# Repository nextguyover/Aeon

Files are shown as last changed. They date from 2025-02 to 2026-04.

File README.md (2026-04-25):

# Aeon

Aeon

Aeon is a solar-powered colour e-ink photo frame designed around the [7.3inch Spectra 6](https://www.waveshare.com/7.3inch-e-paper-hat-e.htm) e-ink display. Powered using energy harvesting, Aeon achieves indefinite operation when placed in a bright indoor environment.

This repository contains the following design files for Aeon. 

- [Firmware](firmware)
- [Image Conversion Script](image_conversion)
- [Schematic and PCB Design](schematic_and_PCB)

See the the [blogpost](https://insertnewline.com/blog/aeon/) for a full write-up and additional file downloads.

Current Aeon version is v2.0, available on the [main branch](https://github.com/nextguyover/Aeon/tree/main). See older versions below:
- [v1.4](https://github.com/nextguyover/Aeon/tree/v1.4) - Using discontinued [7.3inch ACeP](https://www.waveshare.com/7.3inch-e-paper-hat-f.htm) e-ink display

## Firmware

The `/firmware` directory contains the firmware for the STM32 microcontroller.

### Flashing

Before flashing the firmware, the option bytes of the STM32 must be set. Using STM32CubeProgrammer, uncheck nSWBOOT0. The option byte options should look like this:

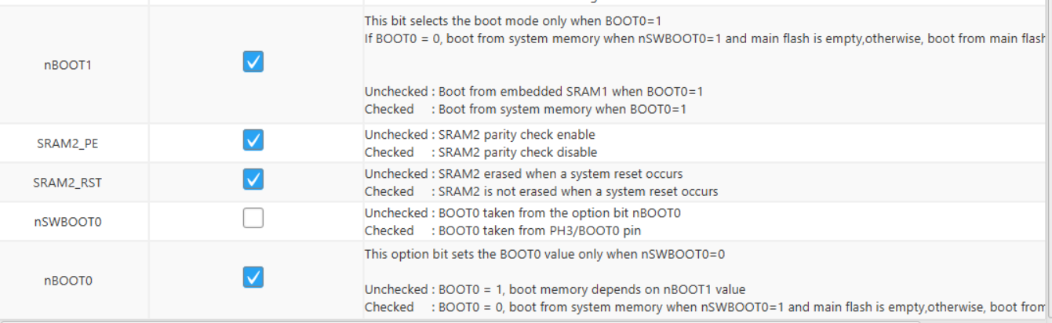
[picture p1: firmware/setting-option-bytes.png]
option bytes


Next, flashing the firmware can be done using the STM32CubeIDE. Your STLink programmer should be connected to the programming pins on the PCB.

### Debugging

The firmware includes several debugging features. 

Any `printf` statements will be outputted to SWO, which can be read using STLink. Additionally, if debug mode is active, any logged data will be stored in an array, and written to the SD card just before going back to sleep. This debug mode is enabled by pressing and **holding** the refresh button to wake the device. The status LED will **flash rapidly** to indicate debug mode is active. Alternatively, the `DEBUG_MODE_FORCE_EN` flag in `main.h` forces debug mode to be enabled. This should be disabled during normal operation to prevent excessive SD card writes.

The `BATT_LOGGING` flag in logs to `/logfiles/batt-charge.csv` on the SD card. This only appends a new line to the file on each wake cycle, so it is safe to leave on for extended periods of time.

### ADC Calibration

The ADC for the battery voltage measurement should be calibrated as the accuracy of different STM32 chips can vary. The calibration process must be done manually by changing [this](/firmware/Core/Src/aeon.c#L108) value in the `aeon.c` file.

## Image Conversion

The `/image_conversion` folder contains a Python script to convert images to the SLIC format, which is the image format Aeon supports. 

### Preparation

Compile the photos you wish to display on Aeon, and save them in a directory. `.jpg`, `.png` and `.heic` files are supported. All images should be the same orientation. If a portrait orientation is chosen, rotate all portrait images 90 degrees clockwise. 

### Usage Instructions

The first step is preparing the SLIC conversion executable.

1. Git clone the SLIC repository `git clone https://github.com/bitbank2/SLIC.git`
2. Change directory `cd SLIC/linux/c_demo/`
3. Compile executable with `make`
4. Copy the executable to the `/image_conversion` directory

Next, install the required Python packages with `pip install -r requirements.txt`.

To convert a directory of images, run `python convert.py <input_dir>` where `<input_dir>` is the directory containing the images to convert. The converted images will be saved in a new directory named `img_out`.

Format the SD card in FAT32. The generated `.slc` files can then be copied to the `/images` directory of the SD card. *Do not rename the generated files.*

## Schematic and PCB Design

The `/schematic_and_PCB` directory contains the KiCad schematic and PCB design files for Aeon.

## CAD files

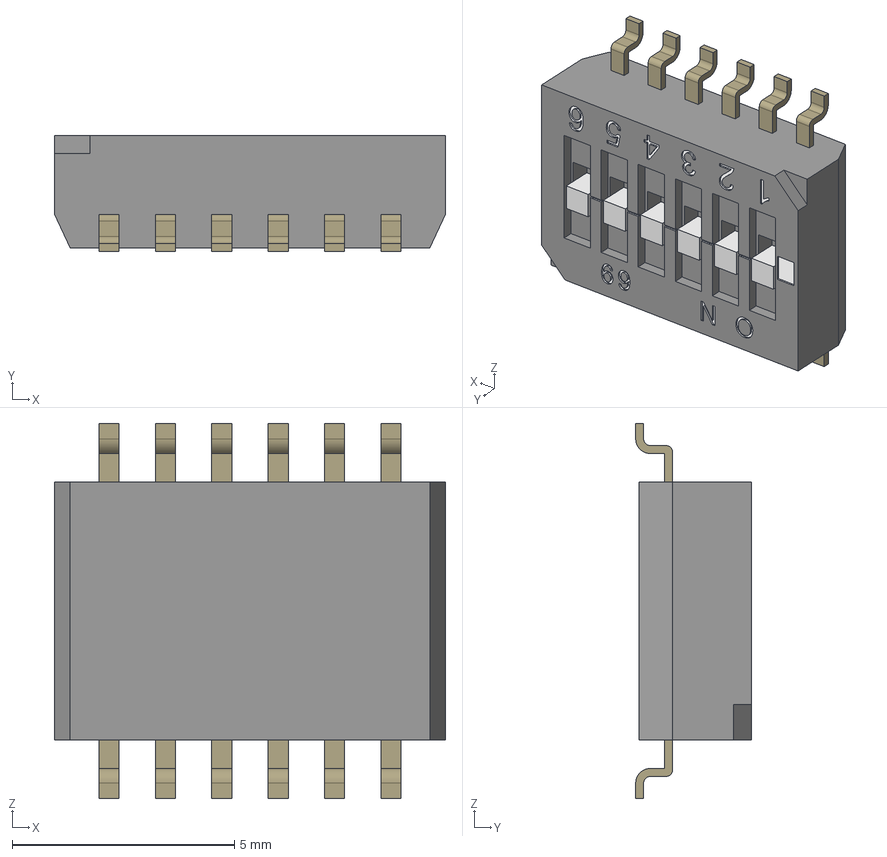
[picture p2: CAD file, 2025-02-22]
schematic_and_PCB/Symbols External/218-6LPSRF/218-6LPSRF.stp
8.79 x 2.60 x 8.44 mm

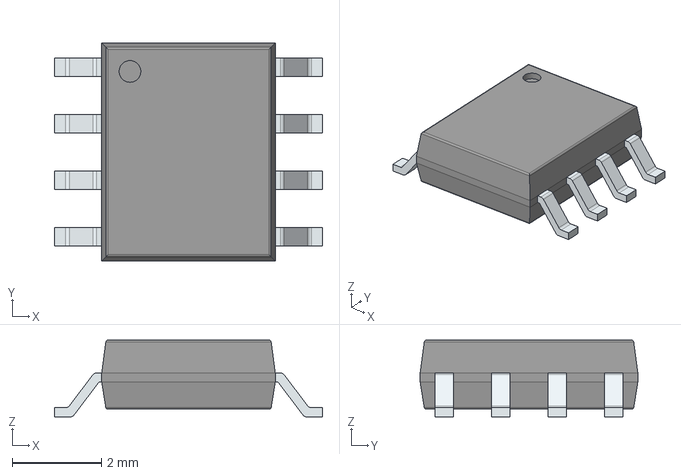
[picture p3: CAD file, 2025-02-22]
schematic_and_PCB/Symbols External/LIB_FM25L04B-GTR/FM25L04B-GTR/3D/FM25L04B-GTR.stp
6.02 x 4.89 x 1.73 mm
PinsArrayLR

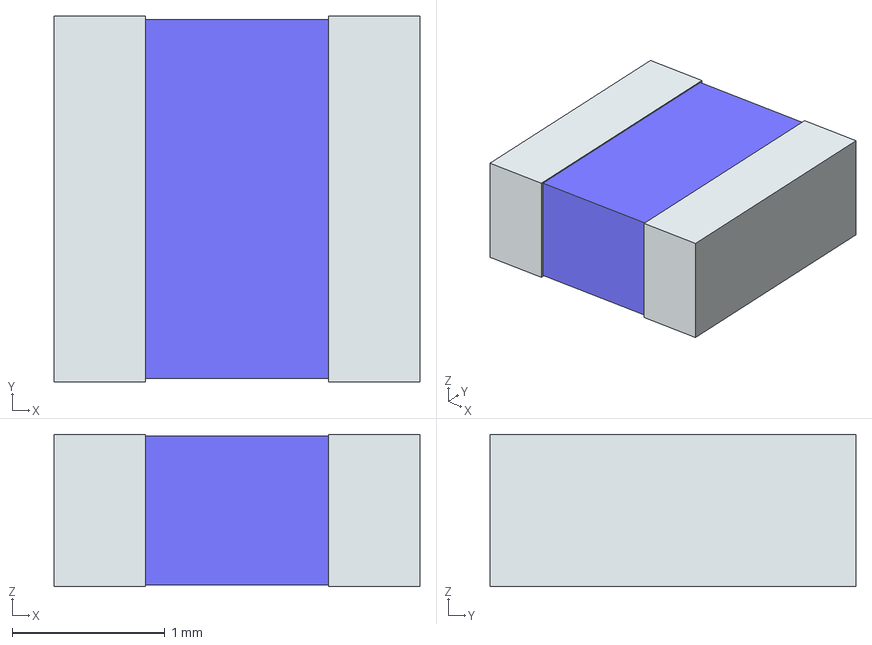
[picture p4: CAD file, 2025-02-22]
schematic_and_PCB/Symbols External/LIB_NRH2410T220MN- inductor 2410/NRH2410T220MN/3D/NRH2410T220MN.stp
2.40 x 2.40 x 1.00 mm
term1
term2

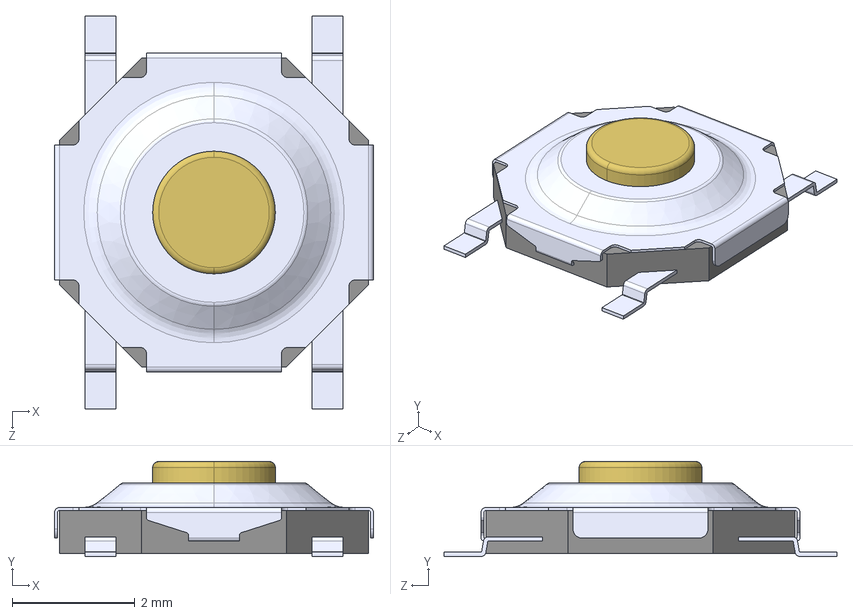
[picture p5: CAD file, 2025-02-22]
schematic_and_PCB/Symbols External/LIB_PTS526_SK15_SMTR2_LFS/PTS526_SK15_SMTR2_LFS.stp
5.20 x 1.55 x 6.40 mm

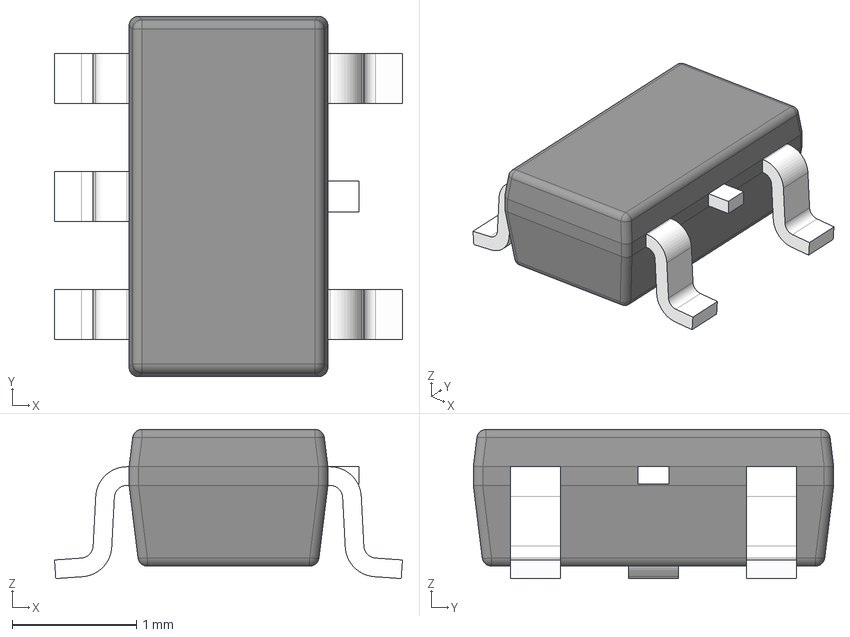
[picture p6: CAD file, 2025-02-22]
schematic_and_PCB/Symbols External/LIB_TPS7A0233PDBVR/TPS7A0233PDBVR.stp
2.80 x 2.90 x 1.20 mm
BODY-SOT
LEAD-SOT x 5
LEAD-DUMMY

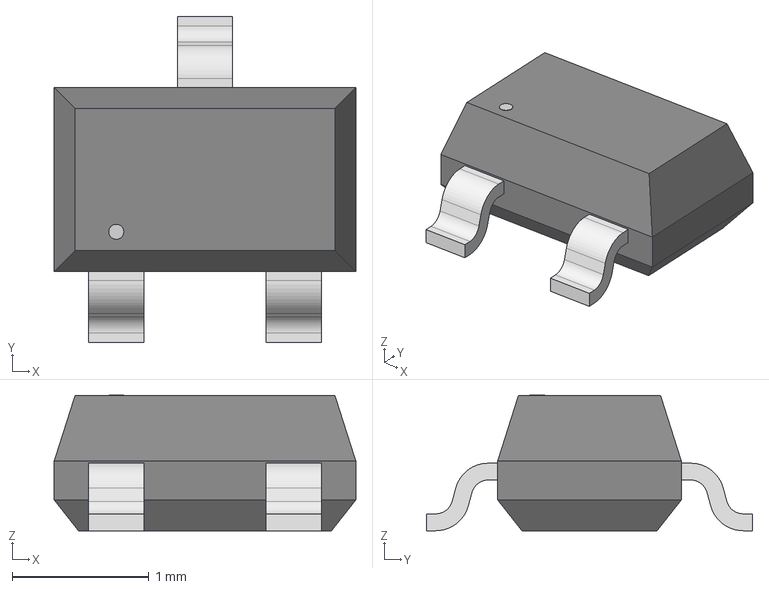
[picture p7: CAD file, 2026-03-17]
schematic_and_PCB/Symbols External/SI1308EDL_T1_GE3/MOSFET_8EDL-T1-GE3_VIS.step
2.21 x 2.39 x 0.993 mm

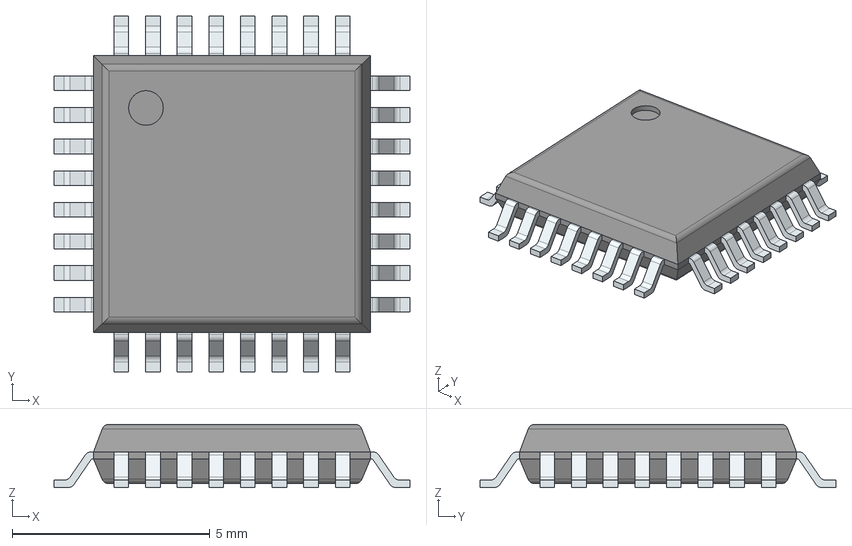
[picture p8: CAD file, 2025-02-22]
schematic_and_PCB/Symbols External/STM32L412K8T6/3D/STM32L412K8T6.stp
9.00 x 9.00 x 1.60 mm
PinsArrayLR
PinsArrayTB

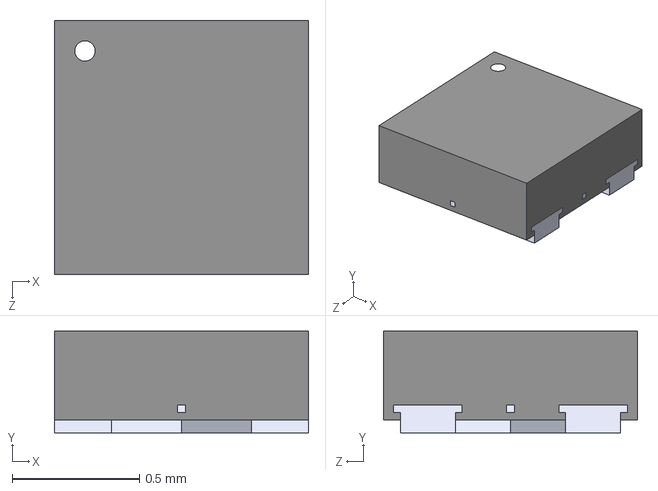
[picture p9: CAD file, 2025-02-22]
schematic_and_PCB/Symbols External/TPS7A0233PDQNR/TPS7A0233PDQNR.step
1.00 x 0.4 x 1.00 mm

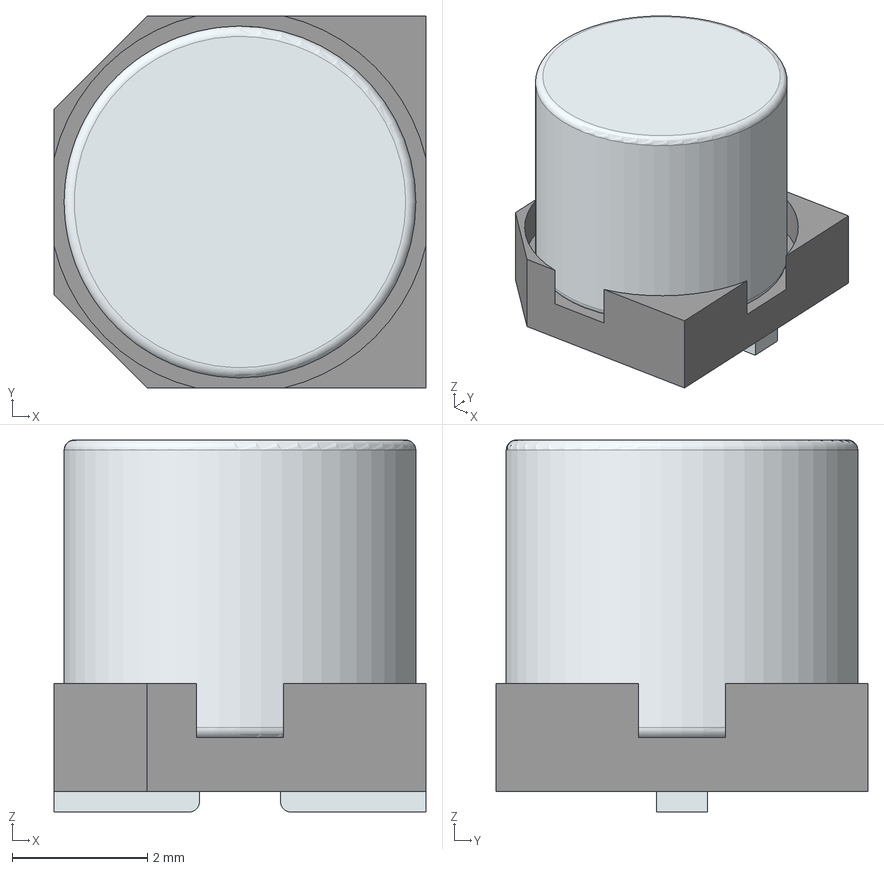
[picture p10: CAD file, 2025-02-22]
schematic_and_PCB/Symbols External/100uF SMD Electrolytic/865080142007.stp
5.50 x 5.50 x 5.50 mm
Base
Pin1Fillet
Pin2Fillet

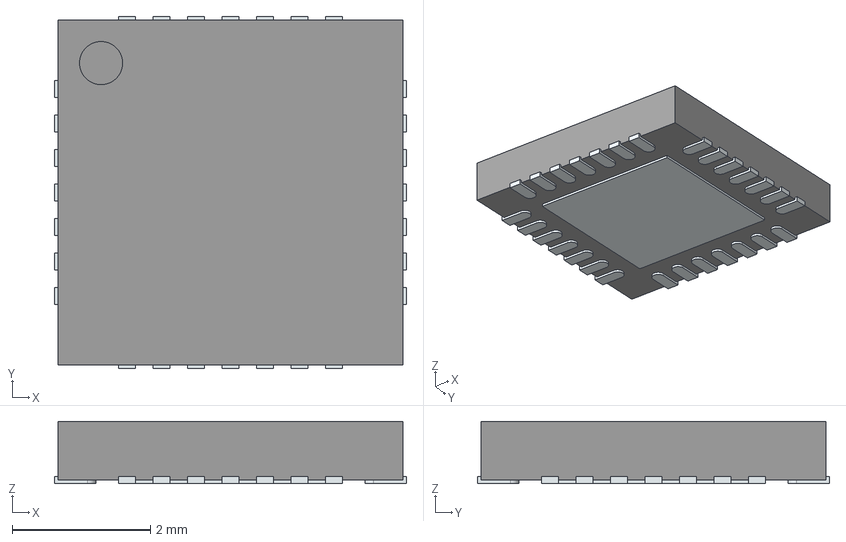
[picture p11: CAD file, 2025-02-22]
schematic_and_PCB/Symbols External/AEM10941-QFN/AEM10941-QFN.stp
5.10 x 5.10 x 0.9 mm
ThermalPin
PinsArrayLR
PinsArrayTB

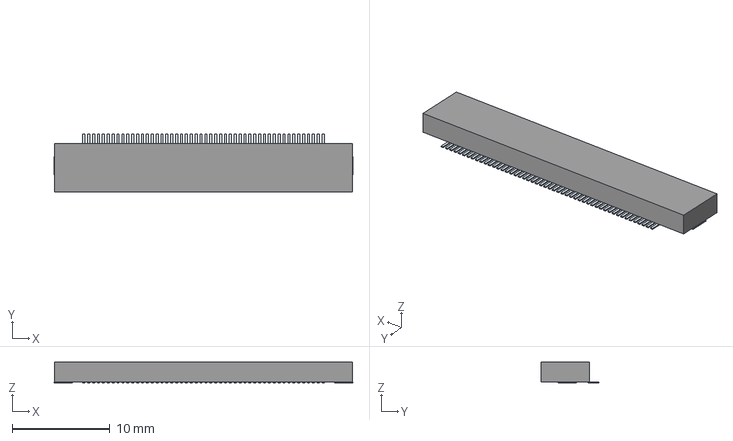
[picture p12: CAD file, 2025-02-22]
schematic_and_PCB/Symbols External/FPC_CONN_2/62684-50110E9ALF.stp
30.6 x 5.97 x 2.10 mm
Pins

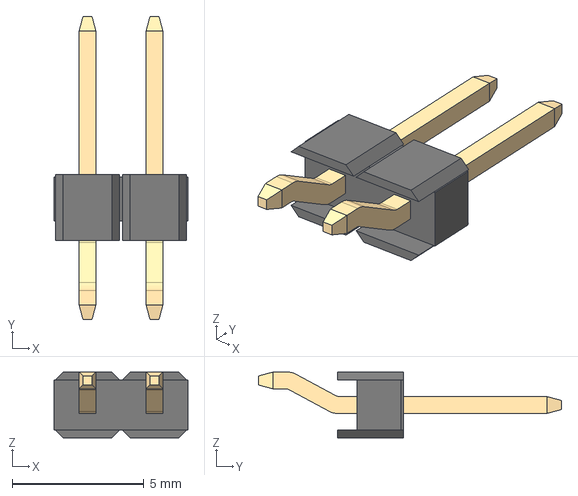
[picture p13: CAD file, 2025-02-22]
schematic_and_PCB/Symbols External/LIB_M20-8890245 - 2-pin-smd connector/M20-8890245/3D/M20-8890245.stp
5.08 x 11.5 x 2.50 mm
M20-88902_MOULD
M20-889_CONTACT x 2

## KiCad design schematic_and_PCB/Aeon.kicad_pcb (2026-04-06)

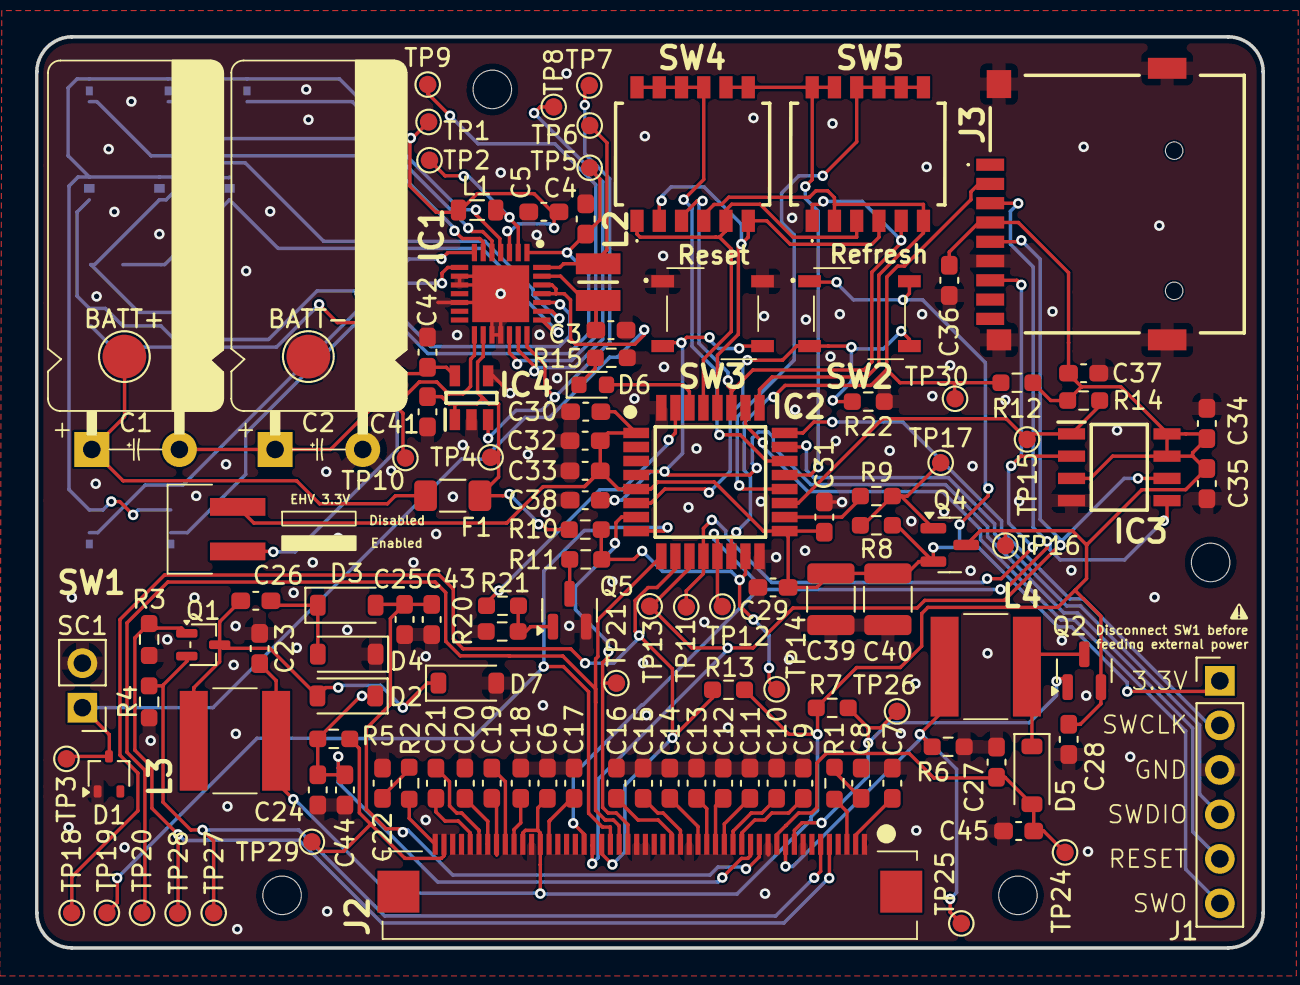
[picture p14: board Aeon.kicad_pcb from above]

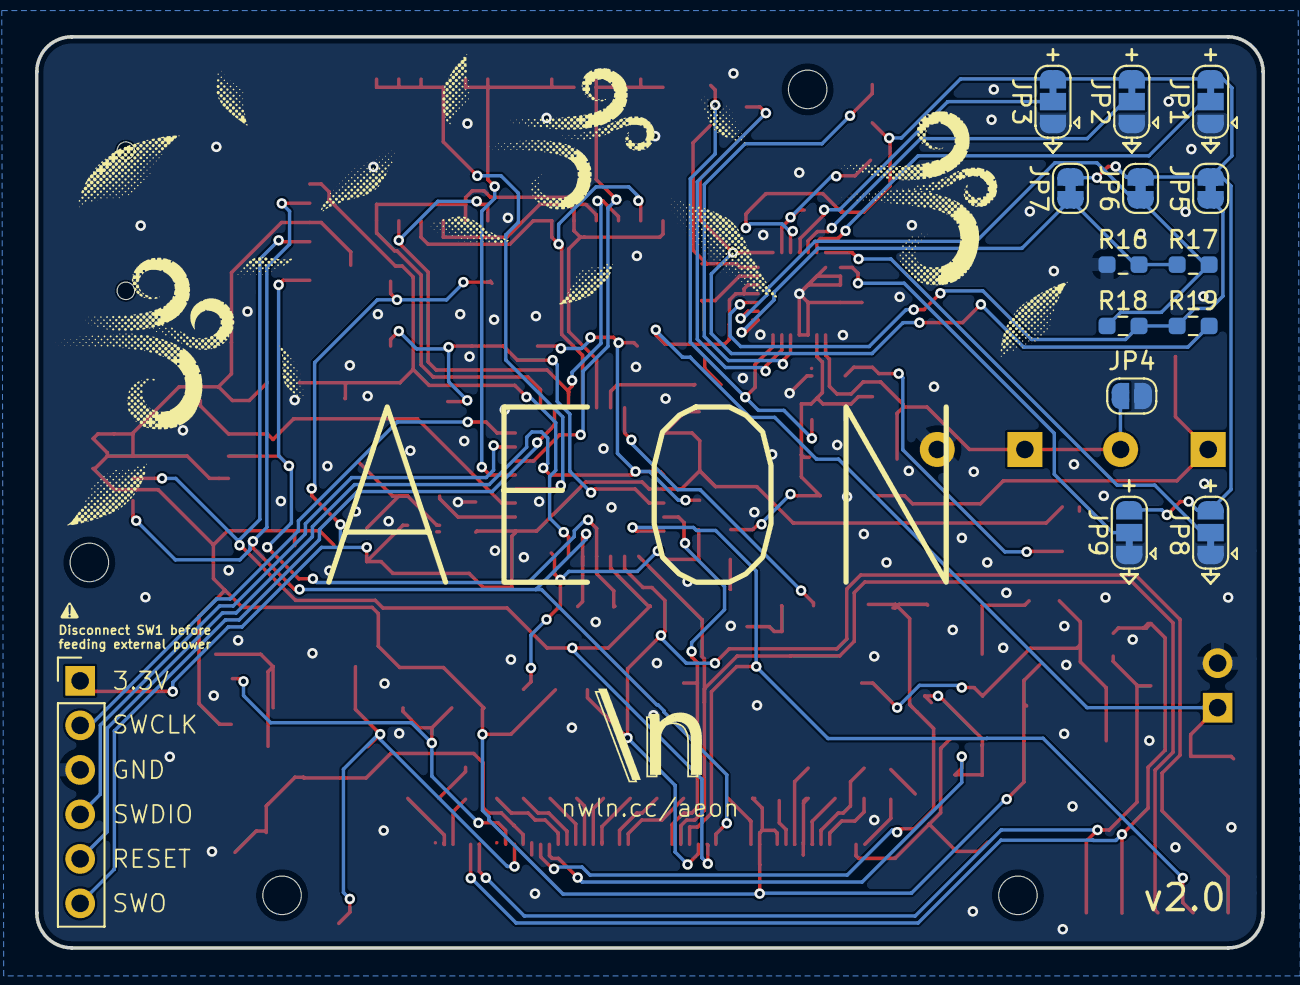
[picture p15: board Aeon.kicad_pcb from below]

Board: 2 copper layers, 70.0 x 52.0 mm, 135 parts (13 on the bottom side), 84 nets.

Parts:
BATT+: TestPoint_Pad_D2.5mm
BATT-: TestPoint_Pad_D2.5mm
C1, C2: 6F 2.7V; SUPERCAP
C3, C5: 10uF; C_0603_1608Metric_Pad1.08x0.95mm_HandSolder
C4: 22uF; C_0603_1608Metric_Pad1.08x0.95mm_HandSolder
C6, C43, C44, C45: 100nF/50V; C_0603_1608Metric_Pad1.08x0.95mm_HandSolder
C7, C22, C23: 4.7uF/25V; C_0603_1608Metric_Pad1.08x0.95mm_HandSolder
C8: 0.47uF/25V; C_0603_1608Metric_Pad1.08x0.95mm_HandSolder
C9, C10, C11, C12, C13, C14, C24, C25, C26, C27: 10uF/25V; C_0603_1608Metric_Pad1.08x0.95mm_HandSolder
C15, C16, C18, C19, C20, C21: 1uF/50V; C_0603_1608Metric_Pad1.08x0.95mm_HandSolder
C17: 2.2uF/6.3V; C_0603_1608Metric_Pad1.08x0.95mm_HandSolder
C28, C29: 4.7uF/10V; C_0603_1608Metric_Pad1.08x0.95mm_HandSolder
C30, C31, C35, C36: 100nF/10V; C_0603_1608Metric_Pad1.08x0.95mm_HandSolder
C32: 10nF/10V; C_0603_1608Metric_Pad1.08x0.95mm_HandSolder
C33: 1uF/10V; C_0603_1608Metric_Pad1.08x0.95mm_HandSolder
C34, C37: 10uF/10V; C_0603_1608Metric_Pad1.08x0.95mm_HandSolder
C38: 0.1uF/10V; C_0603_1608Metric_Pad1.08x0.95mm_HandSolder
C39, C40: 100uF/10V; C_1210_3225Metric
C41, C42: 1uF; C_0603_1608Metric_Pad1.08x0.95mm_HandSolder
D1: Zener_5V; SOT-323_SC-70
D2, D3, D4, D5: MBR0530; D_SOD-123
D6: DEBUG_LED; LED_0603_1608Metric
D7: BZT52C27; D_SOD-123
F1: 750mA Polyfuse; R_1206_3216Metric_Pad1.30x1.75mm_HandSolder
IC1: AEM10941-QFN; QFN50P500X500X90-29N-D
IC2: STM32L412K8T6; QFP80P900X900X160-32N
IC3: FM25L04B-GTR; SOIC127P602X173-8N
IC4: TPS7A0233PDBVR; SOT95P280X145-5N
J1: Conn_01x06_Pin; PinHeader_1x06_P2.54mm_Vertical
J2: FH34SRJ-50S-0.5SH50 - Colour E-Paper; FPC_CONN_2
J3: Micro_SD_Card; MICROSDCARD
JP1, JP2, JP3: SolderJumper_3_Open; SolderJumper-3_P1.3mm_Bridged2Bar23_RoundedPad1.0x1.5mm
JP4: SolderJumper_2_Open; SolderJumper-2_P1.3mm_Open_RoundedPad1.0x1.5mm
JP5, JP6, JP7: SolderJumper_2_Open; SolderJumper-2_P1.3mm_Bridged_RoundedPad1.0x1.5mm
JP8, JP9: SolderJumper_3_Open; SolderJumper-3_P1.3mm_Bridged2Bar12_RoundedPad1.0x1.5mm
L1: 10uH/50mA; L_0805_2012Metric
L2: 22uH/115mA; INDC2424X100N
L3, L4: 10uH/1A; NR6012T100ME_INDUCTOR_6012
Q1: SI1308EDL; SOT-323_SC-70
Q2, Q4: SI2301CDS-T1-E3; SOT-23
Q5: BSS138; SOT-23
R1, R2, R5: 0R; R_0603_1608Metric_Pad0.98x0.95mm_HandSolder
R3, R7, R8, R20: 1M; R_0603_1608Metric_Pad0.98x0.95mm_HandSolder
R4, R6: 0.2R; R_0603_1608Metric_Pad0.98x0.95mm_HandSolder
R9, R10, R21: 4.7K; R_0603_1608Metric_Pad0.98x0.95mm_HandSolder
R11, R12, R13, R14, R22: 10K; R_0603_1608Metric_Pad0.98x0.95mm_HandSolder
R15: 1K; R_0603_1608Metric_Pad0.98x0.95mm_HandSolder
R16, R17, R18, R19: X; R_0603_1608Metric_Pad0.98x0.95mm_HandSolder
SC1: EHV_SRC_Cell; PinHeader_1x02_P2.54mm_Vertical
SW1: SW_EHV_EN; SMD_2x_PIN_HEADER
SW2: REFRESH_BTN; PTS526SMG15JSMTR2LFS
SW3: RESET_BTN; PTS526SMG15JSMTR2LFS
SW4, SW5: SW_DIP_x06_SMD_1.27; 2186LPSRF
TP1, TP2, TP3, TP4, TP5, TP6, TP7, TP8, TP9, TP10, TP11, TP12, TP13, TP14, TP15, TP16, TP17, TP18, TP19, TP20, TP21, TP24, TP25, TP26, TP27, TP28, TP29, TP30: TestPoint_Pad_D1.0mm

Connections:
+3.3V: C29.2, C30.2, C31.2, C32.1, C33.2, C39.2, C40.2, IC2.1 (VDD_1), IC2.5 (VDDA/VREF+), IC2.17 (VDD_2), J1.1, Q4.2 (S), R8.1, SW1.2, SW2.1
+3.3V AUX: C6.2, C23.2, C28.2, C34.1, C35.2, C36.1, C37.2, IC3.3 (~WP), IC3.7 (~HOLD), IC3.8 (VDD), J2.38 (VDD), J2.40 (VDDIO), J3.4 (VDD), L3.1, Q2.2 (S), Q4.3 (D), R7.2, R12.1, R13.1, R14.1, TP16.1
AUX_PWR_EN: IC2.18 (PA8), R9.1
BATT_VDIV_EN: IC2.31 (PH3-BOOT0), R21.1
DISP_BUSY: IC2.9 (PA3), J2.29 (BUSY_N), TP20.1
DISP_CS: IC2.10 (PA4), J2.31 (CS#), R13.2, TP18.1
DISP_D/C: IC2.8 (PA2), J2.30 (D/C#), TP19.1
DISP_GDRC: J2.9 (GDRC), Q2.1 (G), R7.1, TP26.1
DISP_GDRH: J2.5 (GDRH), Q1.1 (G), R3.2, TP28.1
DISP_MOSI: IC2.13 (PA7), IC3.5 (SI), J2.33 (SIO), J3.3 (CMD), TP12.1
DISP_RESEC: J2.10 (RESEC), L4.1, R6.2, TP25.1
DISP_RESEH: J2.6 (RESEH), Q1.2 (S), R4.2, TP27.1
DISP_RST: IC2.7 (PA1), J2.28 (RES#), TP21.1
DISP_SCLK: IC2.11 (PA5), IC3.6 (SCK), J2.32 (SCL), J3.5 (CLK), TP13.1
DISP_VGH: J2.49 (VGH), R5.2, TP29.1
DISP_VGL: C25.2, C43.2, D3.2 (A), J2.13 (VGL)
DISP_VPC: C27.2, C45.2, D5.2 (A), J2.11 (VPC), TP24.1
DISP_VPH: C24.2, C44.2, D2.1 (K), J2.14 (VPH), R5.1
EHV_BATT: C41.1, F1.1, IC1.16 (BATT), IC4.1 (IN), R10.1, TP4.1
EHV_BOOST: C4.2, IC1.1 (BOOST), R19.2, TP5.1
EHV_BUCK: C5.2, IC1.3 (BUCK), JP1.3 (B), JP2.3 (B), JP3.3 (B), JP5.2 (B), JP6.2 (B), JP7.2 (B), JP8.3 (B), JP9.3 (B), L1.1, TP1.1
EHV_LDO_EN: IC1.21 (STATUS[0]), IC4.3 (EN), TP7.1
EHV_SRC: D1.3 (K), IC1.25 (SRC), IC1.26 (SRC), SC1.1 (+), TP3.1
EHV_SWBOOST: IC1.28 (SWBOOST), L2.1, TP6.1
EHV_SWBUCK: IC1.2 (SWBUCK), L1.2, TP2.1
FRAM_CS: IC2.19 (PA9), IC3.1 (~CS), R14.2, TP15.1
FRAM_MISO: IC2.12 (PA6), IC3.2 (SO), J3.7 (DAT0), TP11.1
GND: BATT-.1, C2.2, C3.2, C4.1, C5.1, C6.1, C7.1, C8.1, C9.1, C10.1, C11.1, C12.1, C13.1, C14.1, C15.1, C16.1, C17.1, C18.1, C20.1, C22.1, C23.1, C24.1, C25.1, C27.1, C28.1, C29.1, C30.1, C31.1, C32.2, C33.1, C34.2, C35.1, C36.2, C37.1, C38.2, C39.1, C40.1, C41.2, C42.1, C43.1, C44.1, C45.1, D1.1 (A), D4.1 (K), D7.2 (A), IC1.9 (FB_PRIM_D), IC1.10 (FB_PRIM_U), IC1.12 (ENHV), IC1.17 (PRIM), IC1.18 (ENLV), IC1.29 (PAD_(GND)), IC2.16 (VSS_1), IC2.32 (VSS_2), IC3.4 (VSS), IC4.2 (GND), IC4.4 (NC), J1.3, J2.8 (GND), J2.12 (GND), J2.21 (GNDA), J2.26 (BS0), J2.27 (BS1), J2.39 (GND), J3.6 (VSS), J3.9 (SHIELD), JP1.1 (A), JP2.1 (A), JP3.1 (A), JP4.1 (A), JP8.1 (A), JP9.1 (A), Q5.2 (S), R3.1, R4.1, R6.1, R15.2, R16.1, R20.2, R22.1, SC1.2 (-), SW3.1
unnamed: BATT+.1, C1.1, F1.2
unnamed: C8.2, R1.1
unnamed: C22.2, R2.1
unnamed: C26.2, D2.2 (A), D7.1 (K), L3.2, Q1.3 (D)
unnamed: C26.1, D3.1 (K), D4.2 (A)
unnamed: D5.1 (K), L4.2, Q2.3 (D)
unnamed: D6.2 (A), IC2.30 (PB7)
unnamed: D6.1 (K), R15.1
unnamed: C1.2, C2.1, IC1.15 (BAL), JP4.2 (B), TP10.1
unnamed: C3.1, IC1.27 (BUFSRC), L2.2
unnamed: IC1.6 (CFG[0]), JP1.2 (C)
unnamed: IC1.5 (CFG[1]), JP2.2 (C)
unnamed: IC1.4 (CFG[2]), JP3.2 (C)
unnamed: IC1.8 (SELMPP[0]), JP9.2 (C)
unnamed: IC1.7 (SELMPP[1]), JP8.2 (C)
unnamed: IC1.23 (SET_CHRDY), JP6.1 (A), R17.2, R18.1
unnamed: IC1.22 (SET_OVCH), JP7.1 (A), R16.2, R17.1
unnamed: IC1.24 (SET_OVDIS), JP5.1 (A), R18.2, R19.1
unnamed: IC1.20 (STATUS[1]), TP8.1
unnamed: IC1.19 (STATUS[2]), TP9.1
unnamed: IC2.6 (PA0-CK_IN), R22.2, SW2.2
unnamed: IC2.20 (PA10), SW5.7, SW5.8, SW5.9, SW5.10
unnamed: IC2.21 (PA11), SW4.7, SW4.8, SW5.11, SW5.12
unnamed: IC2.22 (PA12), SW4.9, SW4.10, SW4.11, SW4.12
unnamed: IC2.25 (PA15), SW4.4, SW5.2, SW5.6
unnamed: IC2.15 (PB1), R10.2, R11.1, TP14.1
unnamed: IC2.27 (PB4), SW4.3, SW5.1, SW5.5
unnamed: IC2.28 (PB5), SW4.2, SW4.6, SW5.4
unnamed: IC2.29 (PB6), SW4.1, SW4.5, SW5.3
unnamed: C42.2, IC4.5 (OUT), SW1.1
unnamed: C21.1, J2.45 (CP1N)
unnamed: C21.2, J2.46 (CP1P)
unnamed: C19.1, J2.42 (CP2N)
unnamed: C19.2, J2.43 (CP2P)
unnamed: J2.3 (FPL_VCOM), R1.2
unnamed: C15.2, J2.22 (REFN)
unnamed: C16.2, J2.23 (REFP)
unnamed: C7.2, J2.2 (TFT_VCOM)
unnamed: J2.50 (VCOMBD), R2.2
unnamed: C20.2, J2.44 (VCP1)
unnamed: C18.2, J2.41 (VCP2)
unnamed: C17.2, J2.37 (VDDDO)
unnamed: C9.2, J2.15 (VSH)
unnamed: C11.2, J2.17 (VSH_LV2)
unnamed: C10.2, J2.16 (VSH_LV)
unnamed: C12.2, J2.18 (VSL)
unnamed: C14.2, J2.20 (VSL_LV2)
unnamed: C13.2, J2.19 (VSL_LV)
unnamed: Q4.1 (G), R8.2, R9.2, TP17.1
unnamed: Q5.3 (D), R11.2
unnamed: Q5.1 (G), R20.1, R21.2
SD_CS: IC2.14 (PB0), J3.2 (DAT3/CD), R12.2, TP30.1
SOC_RST: C38.1, IC2.4 (NRST), J1.5, SW3.2
SOC_SWCLK: IC2.24 (PA14), J1.2
SOC_SWDIO: IC2.23 (PA13), J1.4
SOC_SWO: IC2.26 (PB3), J1.6

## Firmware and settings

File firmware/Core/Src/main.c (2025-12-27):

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
/* Includes ------------------------------------------------------------------*/
#include "main.h"

#include "fatfs.h"

/* USER CODE BEGIN Includes */
#include <stdarg.h>  //for va_list var arg functions
#include <stdbool.h>
#include <stdio.h>
#include <string.h>

#include "aeon.h"
#include "disp.h"
#include "fram.h"
#include "sd.h"
#include "slic.h"

/* USER CODE END Includes */

ADC_HandleTypeDef hadc1;

RNG_HandleTypeDef hrng;

RTC_HandleTypeDef hrtc;

SPI_HandleTypeDef hspi1;

/* USER CODE BEGIN PV */

enum wake_reason_t wake_reason;

bool runtime_debug_mode = true;

uint32_t wake_cycle_count;
double batt_voltage;

#define DEBUG_OUTPUT_ARR_SIZE 20000
char debug_output_arr[DEBUG_OUTPUT_ARR_SIZE];
int debug_output_arr_index = 0;

FATFS FatFs;

FIL img_file_ptr;

#define PIXEL_BUF_SIZE 5000
uint8_t pixel_buf[PIXEL_BUF_SIZE];

/* USER CODE END PV */

void SystemClock_Config(void);
static void MX_GPIO_Init(void);
static void MX_ADC1_Init(void);
static void MX_SPI1_Init(void);
static void MX_RTC_Init(void);
static void MX_RNG_Init(void);
/* USER CODE BEGIN 0 */

int __io_putchar(int ch) {
    if ((runtime_debug_mode || DEBUG_MODE_FORCE_EN) &&
        debug_output_arr_index < DEBUG_OUTPUT_ARR_SIZE) {
        debug_output_arr[debug_output_arr_index++] = ch;
    }

    // Write character to ITM ch.0
    ITM_SendChar(ch);
    return (ch);
}

int img_slic_open_callback(const char* filename, SLICFILE* pFile) {
    FRESULT fres;

    fres = f_open(&img_file_ptr, filename, FA_READ);
    if (fres != FR_OK) {
        printf("f_open error (%i)\r\n", fres);
        return -1;
    }

    pFile->fHandle = &img_file_ptr;

    return 0;
}

int img_slic_read_callback(SLICFILE* pFile, uint8_t* pBuf, int32_t iLen) {
    UINT bytesRead;
    FRESULT fres;

    fres = f_read(pFile->fHandle, pBuf, iLen, &bytesRead);
    if (fres != FR_OK) {
        printf("f_read error (%i)\r\n", fres);
        return -1;
    }

    return bytesRead;
}

/* USER CODE END 0 */

/**
 * @brief  The application entry point.
 * @retval int
 */
int main(void) {
    /* USER CODE BEGIN 1 */

    setvbuf(stdout, NULL, _IONBF, 0);  // disable line buffering for printf

    bool wakeup_by_refresh_btn = __HAL_PWR_GET_FLAG(
        PWR_FLAG_WUF1);  // check if wake up was caused by refresh button
    bool wakeup_by_rtc =
        __HAL_RTC_WAKEUPTIMER_EXTI_GET_FLAG();  // check if wake up was caused
                                                // by RTC

    /* USER CODE END 1 */

    /* MCU
     * Configuration--------------------------------------------------------*/

    /* Reset of all peripherals, Initializes the Flash interface and the
     * Systick. */
    HAL_Init();

    /* Configure the system clock */
    SystemClock_Config();

    /* Initialize all configured peripherals */
    MX_GPIO_Init();
    MX_ADC1_Init();
    MX_SPI1_Init();
    MX_FATFS_Init();
    MX_RTC_Init();
    MX_RNG_Init();
    /* USER CODE BEGIN 2 */

    // ================= Initialisation ================= //

    __HAL_PWR_CLEAR_FLAG(
        PWR_FLAG_WU);  // clear wake up flag:
                       // https://wiki.st.com/stm32mcu/wiki/Getting_started_with_PWR#Standby_mode
    __HAL_RTC_WAKEUPTIMER_EXTI_CLEAR_FLAG();

    wake_reason = WAKE_REASON_RESET;

    if (wakeup_by_refresh_btn) {
        wake_reason = WAKE_REASON_STBY_REFRESH_BTN;
        if (DBG) printf("Wake from Standby (Refresh Btn)\n");
    } else if (wakeup_by_rtc) {
        wake_reason = WAKE_REASON_STBY_RTC;
        if (DBG) printf("Wake from Standby (RTC)\n");
    } else {
        if (DBG) printf("Wake from pwr off (Reset)\n");
    }

    SET_AUX_PWR(true);  // enable AUX power rail
    HAL_Delay(10);      // wait for AUX PWR to stabilise
    if (DBG) printf("Enabled AUX PWR\n");

    // check for previous unsafe shutdown, and set the flag to true
    bool previous_unsafe_shutdown = fram_sys_start_unsafe_shutdown_update();
    wake_cycle_count = fram_sys_wake_cycle_count_update();

    if (DBG) {
        printf("Starting iteration %lu\n", wake_cycle_count);
        printf("Previous shutdown was %s\n",
               previous_unsafe_shutdown ? "UNSAFE" : "safe");
    }

    bool sd_avail = sd_init(&FatFs);  // initialise SD card
    if (DBG && !sd_avail)
        printf("SD card not available, will be unable to refresh image\n");

    if (!batt_threshold_check(&batt_voltage)) {
        if (DBG)
            printf("Battery voltage is %.2fV, below threshold of %.2fV\n",
                   batt_voltage, BATT_THRESHOLD);

        if (DISABLE_BATT_THRESHOLD_CHECK) {
            if (DBG)
                printf("Battery threshold check disabled, continuing...\n");
        } else {
            fram_set_sleep_reason(SLEEP_REASON_LOW_BATT);
            enter_sleep(12 * 60 * 60);  // sleep for 12 hours
        }
    }
    if (DBG)
        printf("Battery voltage is %.2fV, above threshold of %.2fV\n",
               batt_voltage, BATT_THRESHOLD);

    // check if BTN_IN is held down to enter debug mode
    if (!check_debug_mode_en()) {
        if (!previous_unsafe_shutdown) {
            runtime_debug_mode = false;
        } else {
            printf("Debug mode enabled due to unsafe shutdown!\n");
        }
    }

    // ================= Step 1 ================= //
    // Check whether to do an image refresh or go back to sleep.

    uint32_t remaining_sleep_duration = fram_get_sleep_duration();
    if (DBG)
        printf("Remaining sleep duration: %lu\n", remaining_sleep_duration);

    uint16_t previous_interval_value =
        fram_get_interval_sw_value();  // get previous interval value

    uint16_t current_toggle_sw_value =
        get_toggle_sw_bits();  // get current toggle switch value

    // extract config values from toggle switch value
    bool refresh_enabled = current_toggle_sw_value & 0x800;  // 12th bit
    bool shuffle_enabled = current_toggle_sw_value & 0x400;  // 11th bit
    uint16_t current_interval_value =
        current_toggle_sw_value & 0x3FF;  // interval value is the lower 10 bits
                                          // of the toggle switch value

    fram_set_interval_sw_value(current_interval_value);
    if (DBG)
        printf(
            "Previous interval switch value: %u, Current interval switch "
            "value: %u\n",
            previous_interval_value, current_interval_value);

    // Conditions to return to sleep
    // 1. Sleep duration not elapsed
    // 2. and Wake up not caused by refresh button
    // 3. and Interval switch value not changed
    if (remaining_sleep_duration != 0 && !wakeup_by_refresh_btn &&
        previous_interval_value == current_interval_value) {
        if (DBG)
            printf(
                "Sleep duration not elapsed... Conditions not met for refresh, "
                "going back to sleep.\n");

        uint32_t next_sleep_duration = calculate_update_sleep_duration(
            remaining_sleep_duration, current_interval_value);

        fram_set_sleep_reason(SLEEP_REASON_NORM_ITER);
        enter_sleep(next_sleep_duration);
    }

    // 4. Refresh not enabled (and not woken by refresh button)
    if (!refresh_enabled && !wakeup_by_refresh_btn) {
        if (DBG) printf("Refresh not enabled... Going back to sleep.\n");

        fram_set_sleep_reason(SLEEP_REASON_REFRESH_DISABLED);
        enter_sleep(12 * 60 * 60);  // sleep for 12 hours
    }

    // ================= Step 2 ================= //
    // If conditions are correct, we need to refresh the image, so next, need to
    // select the image to display.

    if (!sd_avail) {
        if (DBG)
            printf(
                "SD card not available to refresh image... Going back to "
                "sleep.\n");

        fram_set_sleep_reason(SLEEP_REASON_NO_SD);
        enter_sleep(12 * 60 * 60);  // sleep for 12 hours
    }

    char filename[41] = {0};
    bool image_available =
        sd_get_next_image_filename(filename, shuffle_enabled);

    if (!image_available) {
        if (DBG)
            printf("No image available to display... Going back to sleep.\n");

        fram_set_sleep_reason(SLEEP_REASON_NO_IMAGE);
        enter_sleep(12 * 60 * 60);  // sleep for 12 hours
    }

    f_chdir("/images");  // change to images directory

    if (DBG) printf("Opening image file: %s\n", filename);
    SLICSTATE slic_state;
    slic_init_decode(filename, &slic_state, NULL, 0, NULL,
                     img_slic_open_callback, img_slic_read_callback);

    // ================= Step 3 ================= //
    // Display the image

    spi_device_select(AEON_SPI_DISP);
    if (DBG) printf("Initialising display\n");
    disp_init();

    if (DBG) printf("Initialising display registers\n");
    disp_init_regs();

    if (DBG) printf("Clearing display\n");
    disp_clear(DISP_WHITE);

    if (DBG)
        printf("Transferring image data to disp (one dot is %i bytes) -> ",
               sizeof(pixel_buf));

    disp_send_command(0x10);

    int pix_buf_remaining = 0;

    int EDP_width = 400;
    int EDP_height = 480;
    for (int i = 0; i < EDP_height; i++) {
        for (int j = 0; j < EDP_width; j++) {
            if (pix_buf_remaining == 0) {
                spi_device_select(AEON_SPI_SD);

                slic_decode(&slic_state, (uint8_t*)&pixel_buf,
                            sizeof(pixel_buf));
                pix_buf_remaining = sizeof(pixel_buf);

                spi_device_select(AEON_SPI_DISP);

                printf(".");
            }

            // each image byte stores data of two consecutive pixels (4 bits
            // each)
            uint8_t pixel_data = pixel_buf[PIXEL_BUF_SIZE - pix_buf_remaining];

            // this sends two 4-bit pixels as one byte
            disp_send_data(pixel_data);
            pix_buf_remaining--;
        }
    }

    if (DBG) printf("\nCompleted image transfer\n");

    if (DBG) printf("Turning on display\n");
    disp_turn_on();

    spi_device_select(AEON_SPI_SD);

    f_close(&img_file_ptr);

    spi_device_select(AEON_SPI_DISP);

    if (DBG) printf("Display to sleep and shutdown\n");
    disp_sleep();  // put display to sleep
    disp_exit();

    // ================= Step 4 ================= //
    // Finalise stored data and go back to sleep

    uint32_t next_sleep_duration =
        calculate_update_sleep_duration(0, current_interval_value);

    fram_set_sleep_reason(SLEEP_REASON_FIRST_AFTER_REFRESH);
    enter_sleep(next_sleep_duration);

    /* USER CODE END 2 */

    /* Infinite loop */
    /* USER CODE BEGIN WHILE */
    while (1) {
        /* USER CODE END WHILE */

        /* USER CODE BEGIN 3 */
    }
    /* USER CODE END 3 */
}

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


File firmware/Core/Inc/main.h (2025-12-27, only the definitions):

#define BTN_IN_Pin GPIO_PIN_0
#define BTN_IN_GPIO_Port GPIOA
#define DISP_RST_Pin GPIO_PIN_1
#define DISP_RST_GPIO_Port GPIOA
#define DISP_DC_Pin GPIO_PIN_2
#define DISP_DC_GPIO_Port GPIOA
#define DISP_BUSY_Pin GPIO_PIN_3
#define DISP_BUSY_GPIO_Port GPIOA
#define DISP_CS_Pin GPIO_PIN_4
#define DISP_CS_GPIO_Port GPIOA
#define SD_CS_Pin GPIO_PIN_0
#define SD_CS_GPIO_Port GPIOB
#define AUX_PWR_EN_Pin GPIO_PIN_8
#define AUX_PWR_EN_GPIO_Port GPIOA
#define FRAM_CS_Pin GPIO_PIN_9
#define FRAM_CS_GPIO_Port GPIOA
#define SW_OUT_Pin GPIO_PIN_10
#define SW_OUT_GPIO_Port GPIOA
#define SW_OUTA11_Pin GPIO_PIN_11
#define SW_OUTA11_GPIO_Port GPIOA
#define SW_OUTA12_Pin GPIO_PIN_12
#define SW_OUTA12_GPIO_Port GPIOA
#define SW_IN_Pin GPIO_PIN_15
#define SW_IN_GPIO_Port GPIOA
#define SW_INB4_Pin GPIO_PIN_4
#define SW_INB4_GPIO_Port GPIOB
#define SW_INB5_Pin GPIO_PIN_5
#define SW_INB5_GPIO_Port GPIOB
#define SW_INB6_Pin GPIO_PIN_6
#define SW_INB6_GPIO_Port GPIOB
#define DEBUG_LED_Pin GPIO_PIN_7
#define DEBUG_LED_GPIO_Port GPIOB
#define BATT_VDIV_EN_Pin GPIO_PIN_3
#define BATT_VDIV_EN_GPIO_Port GPIOH
#define SD_SPI_HANDLE hspi1
#define DBG_SWO_EN true  // enable SWO debug output
#define DEBUG_MODE_FORCE_EN \
#define DBG (DBG_SWO_EN || runtime_debug_mode)
#define DISABLE_BATT_THRESHOLD_CHECK \
#define BATT_LOGGING true  // enable battery logging to SD card

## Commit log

2025-12-21 correctly interpreting and transferring pixel data
    [main.c]
2025-12-27 double refresh issue fix
    [aeon.c]
2025-12-27 Add battery threshold check functionality control
2026-03-15 Import symbol and footprint libs
2026-03-17 Change electrical design to match Spectra 6 driver reference
    [Aeon.kicad_pcb, Aeon.kicad_sch, MOSFET_8EDL-T1-GE3_VIS.step]
2026-04-06 Update schematic component values
    [Aeon.kicad_pcb, Aeon.kicad_sch]

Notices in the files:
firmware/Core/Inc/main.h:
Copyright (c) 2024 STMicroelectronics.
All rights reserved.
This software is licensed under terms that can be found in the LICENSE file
